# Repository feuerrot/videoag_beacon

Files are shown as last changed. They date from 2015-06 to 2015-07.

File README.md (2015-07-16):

# VideoAG Projekt: Beacon

Hardware ist an unbekannten Orten. Aber für die Aufnahme von Vorlesungen wüssten wir gerne, welche Hardware sich wo befindet. Die Lösung: Ein Beacon.
Auf der Basis eines nRF24L01+ und eines AVR wird so ein preiswertes und stromsparendes Stück Hardware implementiert, die sich jeweils am Equipment befindet und in regelmäßigen Intervallen eine eindeutige ID aussendet. Diese ID wird dann von einem dauerhaft lauschenden Empfänger verarbeitet.

## Projektstatus
Es existiert eine weitgehend stabile und laut Datenblätter stromsparende Idee für die Beacons. Platinen wurden designed und geätzt.

## Todo
* Platinen bestücken
* Firmware entwickeln
* Hardware testen
* Hardware für die Station designen

## Schaltplan und Layout

### Schaltplan
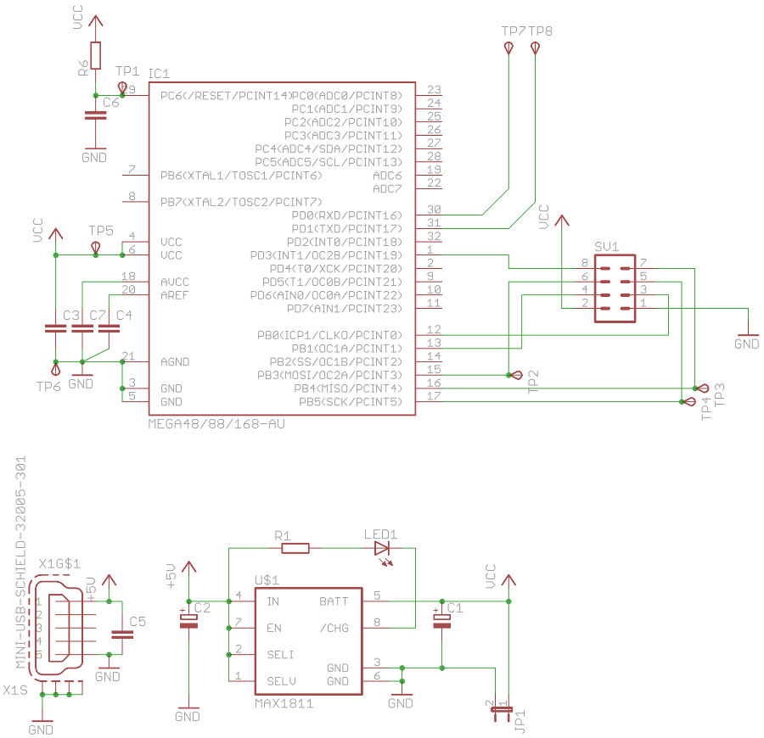
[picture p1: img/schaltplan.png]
Schaltplan der Beaconschaltung


### Layout
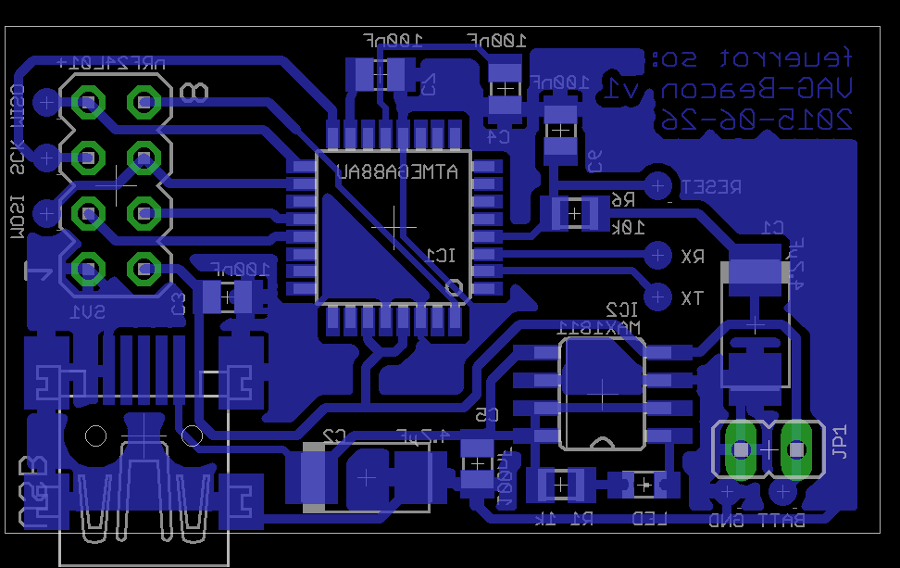
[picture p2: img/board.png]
Layout der Beaconschaltung


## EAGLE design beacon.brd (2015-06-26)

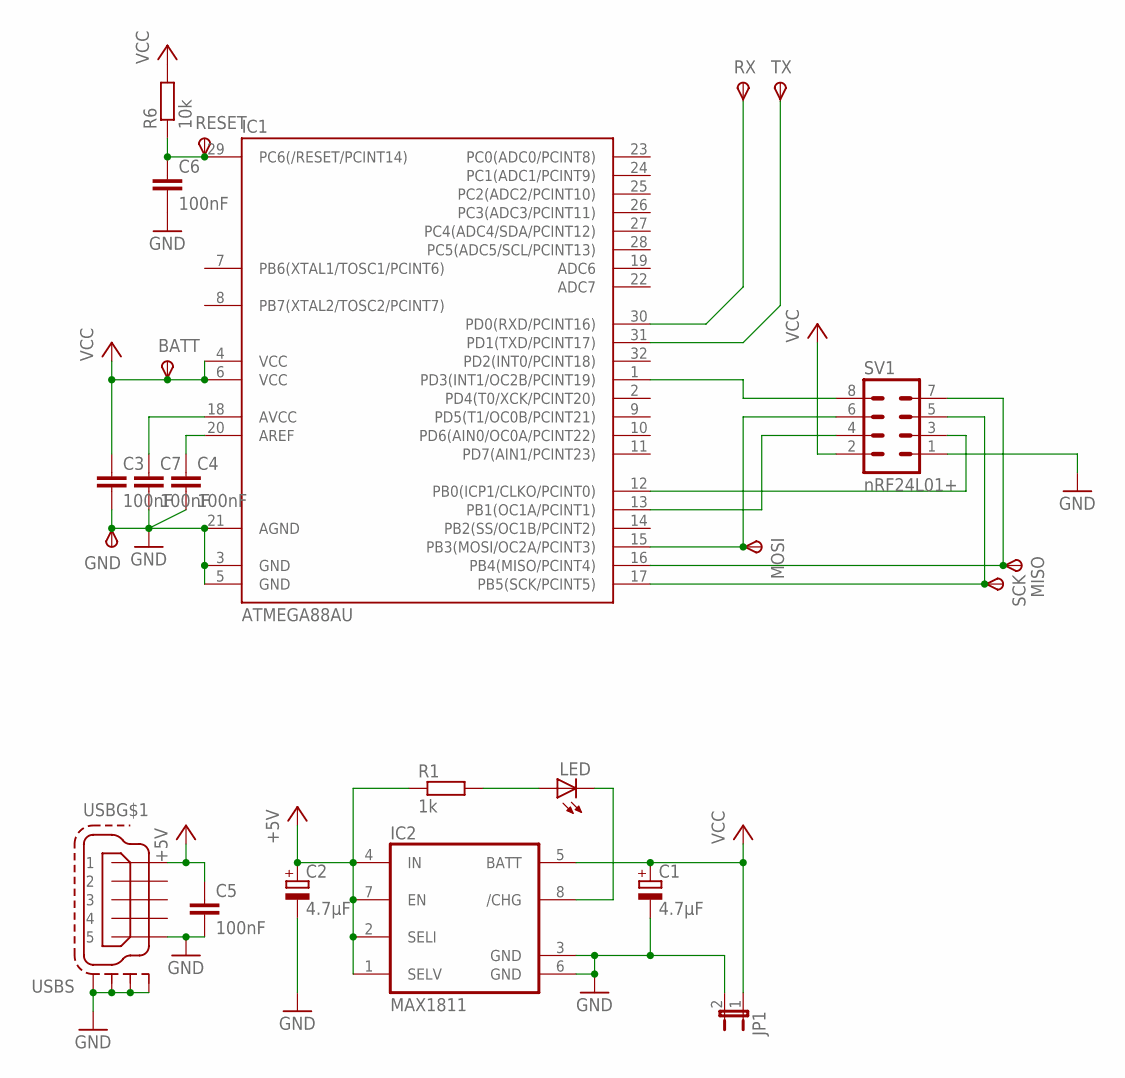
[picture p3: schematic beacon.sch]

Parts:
BATT: TPSB1,27; B1,27
C1, C2: 4.7μF; SMC_C
C3, C4, C5, C6, C7: 100nF; C0805
GND: TPSB1,27; B1,27
IC1: ATMEGA88AU; TQFP32-08
IC2: MAX1811; SO08
JP1: JP1E; JP1
LED: LEDCHIPLED_0805; CHIPLED_0805
MISO: TPSB1,27; B1,27
MOSI: TPSB1,27; B1,27
R1: 1k; M0805
R6: 10k; M0805
RESET: TPSB1,27; B1,27
RX: TPSB1,27; B1,27
SCK: TPSB1,27; B1,27
SV1: nRF24L01+; MA04-2
TX: TPSB1,27; B1,27
USB: MINI-USB-SCHIELD-32005-301; 32005-301

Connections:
+5V: C2.+, C5.1, IC2.1 (SELV), IC2.2 (SELI), IC2.4 (IN), IC2.7 (EN), R1.1, USB.1
AREF: C4.1, IC1.20 (AREF)
AVCC: C7.1, IC1.18 (AVCC)
GND: C1.-, C2.-, C3.2, C4.2, C5.2, C6.2, C7.2, GND.TP, IC1.3 (GND), IC1.5 (GND), IC1.21 (AGND), IC2.3 (GND), IC2.6 (GND), JP1.2, SV1.1, USB.5, USB.M1 (S1), USB.M2 (S2), USB.M3 (S3), USB.M4 (S4)
INT1: IC1.1 (PD3(INT1/OC2B/PCINT19)), SV1.8
MISO: IC1.16 (PB4(MISO/PCINT4)), MISO.TP, SV1.7
MOSI: IC1.15 (PB3(MOSI/OC2A/PCINT3)), MOSI.TP, SV1.6
unnamed: LED.A, R1.2
unnamed: IC2.8 (/CHG), LED.C
PB0: IC1.12 (PB0(ICP1/CLKO/PCINT0)), SV1.3
PB1: IC1.13 (PB1(OC1A/PCINT1)), SV1.4
RESET: C6.1, IC1.29 (PC6(/RESET/PCINT14)), R6.1, RESET.TP
RX: IC1.30 (PD0(RXD/PCINT16)), RX.TP
SCK: IC1.17 (PB5(SCK/PCINT5)), SCK.TP, SV1.5
TX: IC1.31 (PD1(TXD/PCINT17)), TX.TP
VCC: BATT.TP, C1.+, C3.1, IC1.4 (VCC), IC1.6 (VCC), IC2.5 (BATT), JP1.1, R6.2, SV1.2

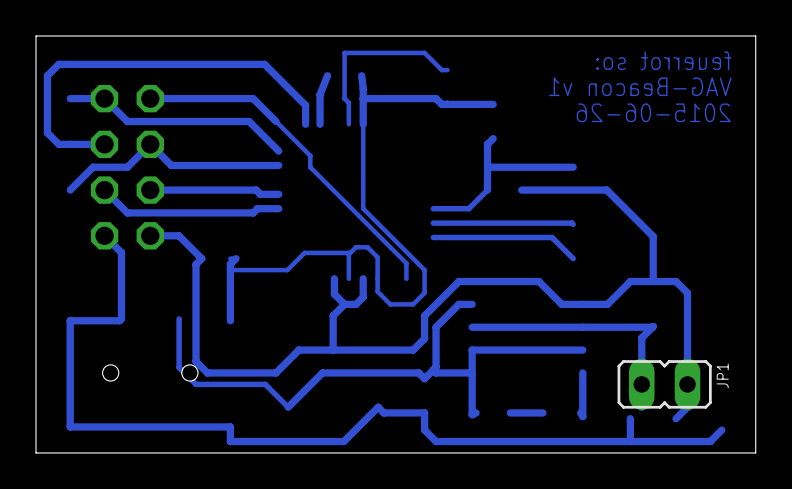
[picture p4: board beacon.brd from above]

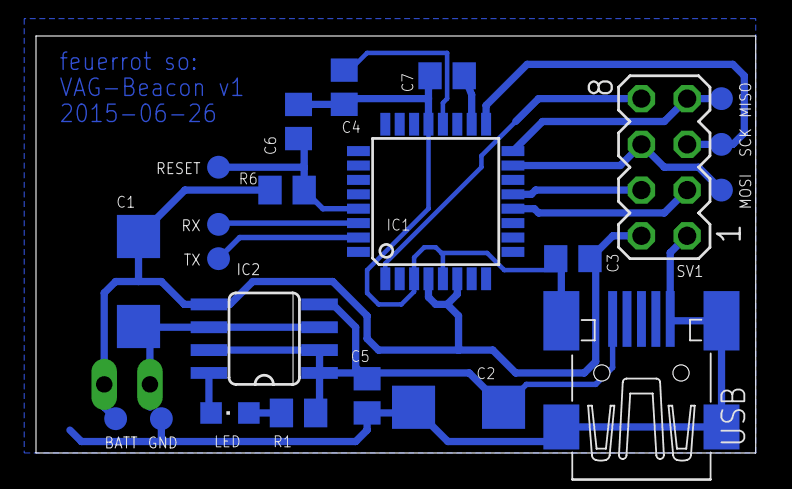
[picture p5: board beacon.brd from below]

Board: 2 copper layers, 40.0 x 23.2 mm, 23 parts (22 on the bottom side), 16 nets.

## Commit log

2015-06-26 update name+value
    [beacon.brd, beacon.sch]
2015-06-26 fix board image
